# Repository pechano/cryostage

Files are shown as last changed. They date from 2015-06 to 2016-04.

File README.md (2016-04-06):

# cryostage

Contained within the /Cryostage repository is all the resources needed to use the Arduino controlled cryostage by Johannes Lørup Buch.

This includes:
	The Arduino sketch
	
	EAGLE files for schematic and PCB (ressources)
	
	Schematics of any lasercut objects used in the project
	
	The scientific poster used to present the project

The project was a part of my PhD thesis and anything contained here has been used purely for academic purposes. 
The original research article can be found at: http://www.sciencedirect.com/science/article/pii/S0011224016300372

###########
Arduino libraries used:
###########

	MAX31855.h //Library by Rob Tillaart. Used for communicating with the MAX31855 chip. https://github.com/RobTillaart/Arduino/tree/master/libraries/MAX31855
  	PID_v1.h //The Arduino PID algorithm by Brett Beauregaard, used to control temperature in setpoint mode. https://github.com/br3ttb/Arduino-PID-Library
  	rgb_lcd.h //Grove LCD RGB Backlight library. https://github.com/Seeed-Studio/Grove_LCD_RGB_Backlight    
	math.h //Math functions used in thermistor calculations.
	Wire.h //I2C library used for communicating with the LCD.

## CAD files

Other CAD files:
resources/Version 3/cooling block.skp

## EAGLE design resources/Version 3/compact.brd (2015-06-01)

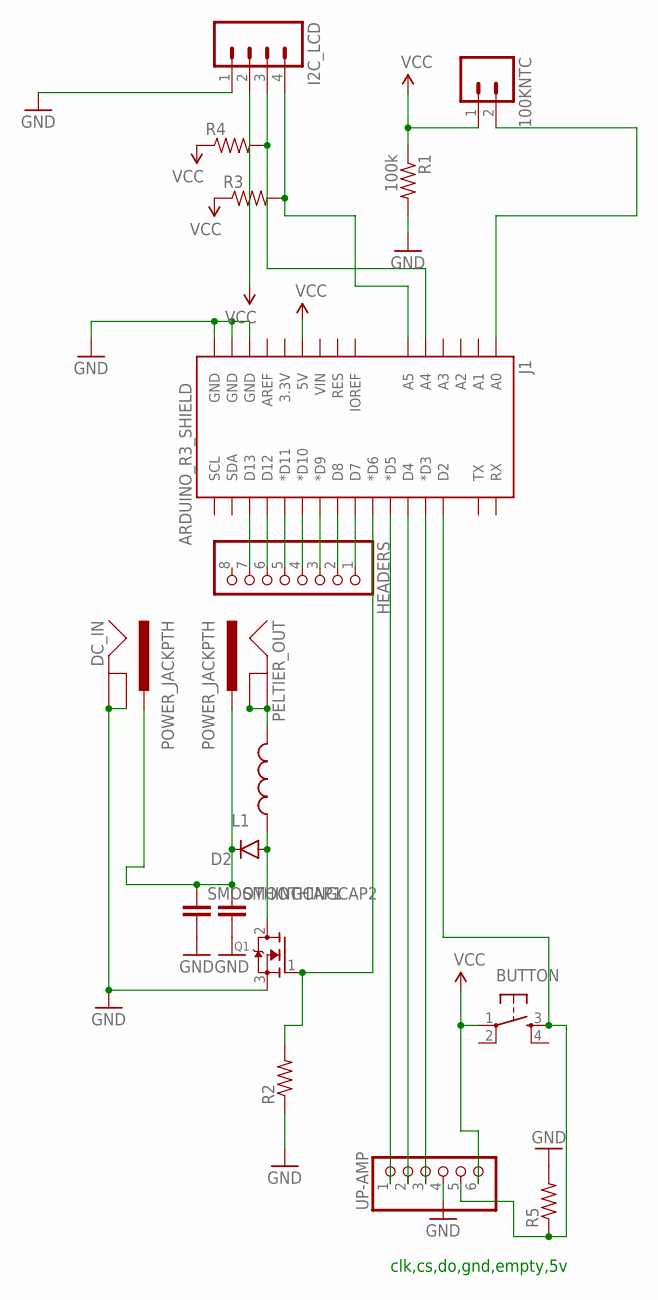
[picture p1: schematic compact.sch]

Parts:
100KNTC: M02LOCK; 1X02_LOCK
BUTTON: TAC_SWITCHPTH; TACTILE-PTH
D2: DIODEPTH; DIODE-1N4001
DC_IN: POWER_JACKPTH; POWER_JACK_PTH
HEADERS: PINHD-1X8BIG; 1X08-BIG
I2C_LCD: M04JST; 1X04-1.5MM_JST
J1: ARDUINO_R3_SHIELD; UNO_R3_SHIELD
L1: INDUCTORRLB0912; RLB0912
PELTIER_OUT: POWER_JACKPTH; POWER_JACK_PTH
Q1: MOSFET-NGDS_TO220V; TO220V
R1: 100k; AXIAL-0.4
R2, R3, R4, R5: RESISTORPTH-1/4W; AXIAL-0.4
SMOOTHINGCAP1, SMOOTHINGCAP2: CAPPTH3; CAP-PTH-LARGE
UP-AMP: PINHD-1X6; 1X06

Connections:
GND: DC_IN.GND, DC_IN.GNDBREAK, I2C_LCD.1, J1.GND@0 (GND), J1.GND@1 (GND), J1.GND@2 (GND), Q1.3 (S), R1.P$2 (2), R2.P$1 (1), R5.P$2 (2), SMOOTHINGCAP1.2, SMOOTHINGCAP2.2, UP-AMP.4
unnamed: D2.C, DC_IN.PWR, PELTIER_OUT.PWR, SMOOTHINGCAP1.1, SMOOTHINGCAP2.1
unnamed: I2C_LCD.3, J1.A4, R4.P$2 (2)
unnamed: J1.D6 (*D6), Q1.1 (G), R2.P$2 (2)
unnamed: J1.D5 (*D5), UP-AMP.1
unnamed: J1.D4, UP-AMP.2
unnamed: J1.D3 (*D3), UP-AMP.3
unnamed: D2.A, L1.1, Q1.2 (D)
unnamed: I2C_LCD.4, J1.A5, R3.P$2 (2)
unnamed: BUTTON.3, J1.D2, R5.P$1 (1), UP-AMP.5
unnamed: 100KNTC.2, J1.A0
unnamed: HEADERS.1, J1.D7
unnamed: HEADERS.2, J1.D8
unnamed: HEADERS.3, J1.D9 (*D9)
unnamed: HEADERS.4, J1.D10 (*D10)
unnamed: HEADERS.5, J1.D11 (*D11)
unnamed: HEADERS.6, J1.D12
unnamed: HEADERS.7, J1.D13
unnamed: L1.2, PELTIER_OUT.GND, PELTIER_OUT.GNDBREAK
VCC: 100KNTC.1, BUTTON.1, I2C_LCD.2, J1.5V, R1.P$1 (1), R3.P$1 (1), R4.P$1 (1), UP-AMP.6

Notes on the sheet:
clk,cs,do,gnd,empty,5v

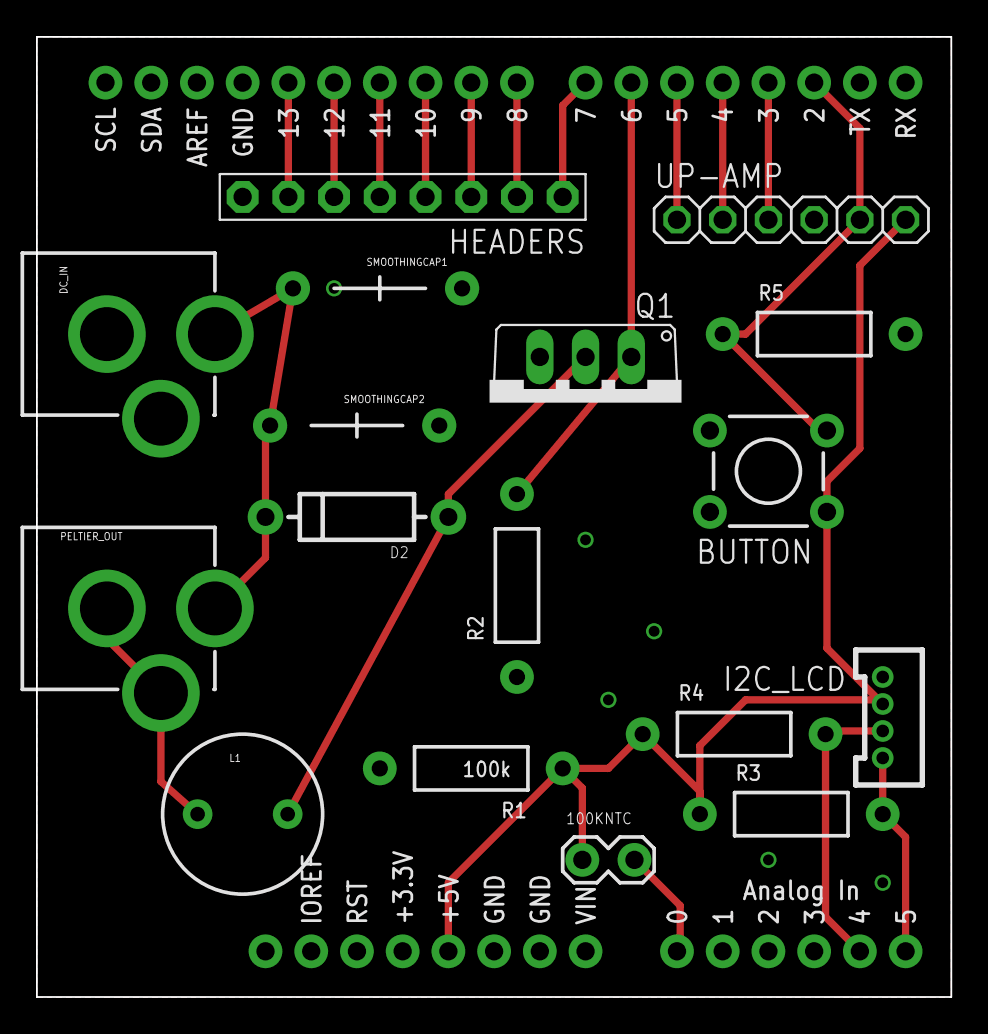
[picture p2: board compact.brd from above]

Board: 2 copper layers, 50.8 x 53.3 mm, 18 parts (0 on the bottom side), 20 nets.

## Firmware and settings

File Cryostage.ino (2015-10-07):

/*

***************************************************************
* Cryostage control - Version 1.0.0
* by Johannes Lørup Buch <jloerup@gmail.com>
*
* This sketch is licensed under a GPLv3 License and is purely for academic purposes.
***************************************************************

*/


//****************************LIBRARIES****************************


    #include "SPI.h" //SPI Library supplied with the Arduino. A dependency of the Adafruit MAX31855 library.
    #include <PID_v1.h> //The Arduino PID algorithm by Brett Beauregaard, used to control temperature in setpoint mode. https://github.com/br3ttb/Arduino-PID-Library
    #include <math.h> //Math functions used in thermistor calculations.
    #include <Wire.h> //I2C library used for communicating with the LCD.
    #include "rgb_lcd.h" //Grove LCD RGB Backlight library. https://github.com/Seeed-Studio/Grove_LCD_RGB_Backlight


//****************************PINS*********************************

//Define MOSFET pin. PWM output from the PID control will go through this pin
    int IRL540 = 6;

//Initiate pins used for buttons on the board and on the box
    int boardButton = 2;
    int freezeButton = 7;
    int PIDButton = 8;
    int loadButton = 9;
    int topButton = 10;
    
//Initiate pins used for status LED and microscope light    
    int freezeLED =13;
    int PIDLED = 12;
    int microscopeLED = 11;
   
 

//************************VARIABLES******************************


//Define PID variables
    double Setpoint, Input, Output;
    PID myPID(&Input, &Output, &Setpoint,5,1,1, REVERSE);

//Define constants and variables for temperature calculation, following Steinhart-Hart.
    float T0 = 298.15;
    float B = 3950;//B-value from the datasheet of the 100k NTC.
    float R0 = 75400;//Measured on 100k resistor with multimeter.
    float Ti = 0;
    float T = 0;
    float R = 0;

//Variables needed for voltage divider at the 100k NTC on A2.
    int signal;
    float vout;
    float vin = 3.30;//Measured between 3.3v(aref) and GND on the Arduino, using a multimeter.

//Initiate the tempstate variable which decides the mode of action for temperature control. The initial value "0" corresponds to load (PWM=0).    
    int tempstate = 0;

//Initiate 16x2 Grove RGB LCD v2.0. The device uses I2C, so SDA is connected to A4 and SCL connected to A5.
    rgb_lcd lcd;
    int colorR = 255;
    int colorG = 0;
    int colorB = 0;

//Variable used to store incoming serial data. The stored value can be used as setpoint for the PID control
    float incoming = 2;

//Voltage divider input on analog pin 2. 
    float potSignal;
    int light;

//Define variables used in timekeeping.
    unsigned long previousTimeLCD = 0;
    unsigned long currentTimeLCD = 0;
    int intervalLCD= 500;

    unsigned long previousTimeSerial = 0;
    unsigned long currentTimeSerial = 0;
    int intervalSerial = 1000;

//**************************SETUP SETUP SETUP SETUP SETUP****************************

void setup(){

    //3.3V (AREF) is used in place of the 5V rail to reduce noise in thermistor readings
        analogReference(EXTERNAL);

    //Define pinmodes for MOSFET, button and optional LED pin
        pinMode(boardButton,INPUT);
        pinMode(freezeButton,INPUT);
        pinMode(PIDButton,INPUT);
        pinMode(loadButton,INPUT);
        pinMode(topButton,INPUT);

        pinMode(freezeLED,OUTPUT);
        pinMode(PIDLED,OUTPUT);
        pinMode(microscopeLED,OUTPUT);

        pinMode(IRL540,OUTPUT);

    //Init PID control
        Input = T;
        Setpoint = 2;

    //Turn on PID
        myPID.SetMode(AUTOMATIC);
  
    //Initiate serial connection and print a test message
        Serial.begin(9600);
        Serial.println("Setup successful");
        delay(500);
        Serial.println("Going to Load");
        delay(500);

    //Start the LCD, say hello and clear
        lcd.begin(16, 2);
        lcd.setRGB(colorR, colorG, colorB);
        lcd.print("Temperature LCD");
        delay(1000);
        lcd.clear();
}

/*
**************************LEWP LEWP LEWP LEWP LEWP LEWP****************************
*/

void loop(){
    
     //Calculate temperature from thermistor connected to A0

        signal = analogRead(A0);
        vout = signal;
        vout = (vout/1023)*vin;
        R = (R0*vout)/(vin-vout);
   
        Ti = (1/T0)+(1/B)*log(R/R0);
        T = 1/Ti; 
        T = T - 273.15;
        

    //BoardButton press sets the temperature state to 3(Potentiometer PID with microscope light)

        if  (digitalRead(boardButton)==HIGH) {
            tempstate = 3;
        }
    
    //LoadButton press sets the tempstate to 0 (Load: PWM=0)

        if  (digitalRead(loadButton)==HIGH) {
            tempstate = 0; 
        }

    //PidButton press sets the tempstate to 1, which is PID control from serial setpoint.

        if  (digitalRead(PIDButton)==HIGH) {
            tempstate = 1;
             
        }

    //Freezebutton press sets the tempstate to 2, which is deep freeze. PWM is 255

        if  (digitalRead(freezeButton)==HIGH) {
            tempstate = 2;
        }
    
    //Topbutton has the same function as boardbutton, it is just at a more convenient position for the user.

        if  (digitalRead(topButton)==HIGH) {
            tempstate = 3;
        }
  

    //Depending on the current tempstate(0-3) the cryostage will do several specific actions.

        switch(tempstate){

            case 0://Tempstate is at the load position, low lights and low cooling
                Output = 20;
                analogWrite(IRL540,Output);
                digitalWrite(PIDLED, LOW);
                digitalWrite(freezeLED, LOW);
                analogWrite(microscopeLED,30);
                colorR = 0;colorG=255;colorB=0;
                lcd.setRGB(colorR, colorG, colorB);
            break;

            case 1://Tempstate is at the PID position, meaning the PID algorithm will run and lights will be turned on
                Setpoint = incoming;
                light = 255;
                digitalWrite(PIDLED,HIGH);
                digitalWrite(freezeLED,LOW);
                analogWrite(microscopeLED,light);
                colorR=255-int(Output);colorG=0;colorB=int(Output);//LCD backlight is set according to cooling power. 255=blue, 0=red.
                lcd.setRGB(colorR, colorG, colorB);
            
                //PID Control with quality control, using the TC value from the beginning of the loop.
                    Input = T;
                    myPID.Compute();
                    analogWrite(IRL540,Output);
            break;

            case 2://Tempstate is deep freeze, meaning the Peltier PWM will be set to 255
                Output = 255;
                analogWrite(IRL540,Output);
                digitalWrite(freezeLED,HIGH);
                digitalWrite(PIDLED,LOW);
                digitalWrite(microscopeLED,HIGH);

                colorR = 0;colorG=0;colorB=255;
                lcd.setRGB(colorR, colorG, colorB);

            break;

            case 3://Tempstate 3 is the same as PID, but setpoint is determined by the potentiometer on A2. The LCD backlight is also set to 30, same as PID mode.
                potSignal = analogRead(A2);   
                potSignal = potSignal - 511;
                potSignal = potSignal/50;
                Setpoint = potSignal;
                Input = T;
                myPID.Compute();
                
                analogWrite(IRL540,Output);
                digitalWrite(PIDLED,LOW);
                digitalWrite(freezeLED, LOW);
                digitalWrite(microscopeLED,HIGH);

                colorR = 255;colorG=255;colorB=255;
                lcd.setRGB(colorR, colorG, colorB);

            break;

    }


    //Receive setpoint from serial, if available. 

        if  (Serial.available() > 0 ){
	        incoming = Serial.parseFloat();//The setpoint is stored in the "incoming" variable. It is only used in tempstate=1
                
        }



 

    //Update the LCD if the intervalLCD time has passed
        
        currentTimeLCD = millis();
        if  ( currentTimeLCD - previousTimeLCD > intervalLCD) {
    
            //Cursor is set for first line and TC temperature is printed
                lcd.setCursor(0,0);
                lcd.print("TR:");
                lcd.setCursor(3,0);
                lcd.print(T);
                lcd.setCursor(8,0);
                lcd.print("State: ");
                lcd.setCursor(15,0);
                lcd.print(tempstate);
         

            //Cursor is set for the second line and setpoint + PWM are printed   
                lcd.setCursor(0,1);
                lcd.print("SP:");
                lcd.setCursor(3,1);
                lcd.print(Setpoint);
                lcd.setCursor(8, 1);
                lcd.print("PWM:");
                lcd.setCursor(12,1);
                lcd.print(Output);

            //One cycle of LCD update has been executed and the timer is reset
                previousTimeLCD = currentTimeLCD ;  

        }

    //Serial communication is on a different timer and is checked like the LCD timer
        currentTimeSerial = millis();
        if  ( currentTimeSerial - previousTimeSerial > intervalSerial ) {

            //Print the incoming data as a confirmation
    	   	    Serial.print("Received setpoint: ");
    	   	    Serial.print(Setpoint);
    	   	    Serial.println(" C");
                    Serial.println(light);
    
            //Print temperature and duty cycle

                Serial.print("100kNTC : ");
                Serial.println(T);
                
            //Reset the Serial timer for next cycle
                previousTimeSerial = currentTimeSerial;  
        }
}

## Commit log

2015-05-07 07052015 problemer med NAN
    [Cryostage.ino]
2015-05-11 code cleanu and commenting. button for potential white LED was added
2015-05-28 28/05/15 version. Code is nearing completion. The thermistor is no longer used, but has been replaced by a pot at A0. RGB_LCD has been fully implemented and so has push buttons for the enclosure
    [Cryostage.ino]
2015-05-29 29052015. The code is nearing completion. A secondary temperature source has been implemented in the form of a 100k NTC on pin A0. The pot has been moved to A2. The Adafruit MAX31855 library will pro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
    [Cryostage.ino]
2015-06-01 first update from windows. Adafruit_max31855 has been replaced by MAX31855 by Rob Tillaart.
    [Cryostage.ino]
2015-06-01 added the version 3 PCB from EAGLE
    [compact.brd]
2015-06-01 added the schematic for version 3 from EAGLE
    [compact.sch]
2015-06-01 version 3 cooling block design from SketchUp
    [cooling block.skp]
2015-10-07 Added license
    GPLv3 license text added to comply with the PID library.

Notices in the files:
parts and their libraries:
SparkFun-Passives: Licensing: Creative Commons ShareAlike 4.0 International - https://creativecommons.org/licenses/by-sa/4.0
